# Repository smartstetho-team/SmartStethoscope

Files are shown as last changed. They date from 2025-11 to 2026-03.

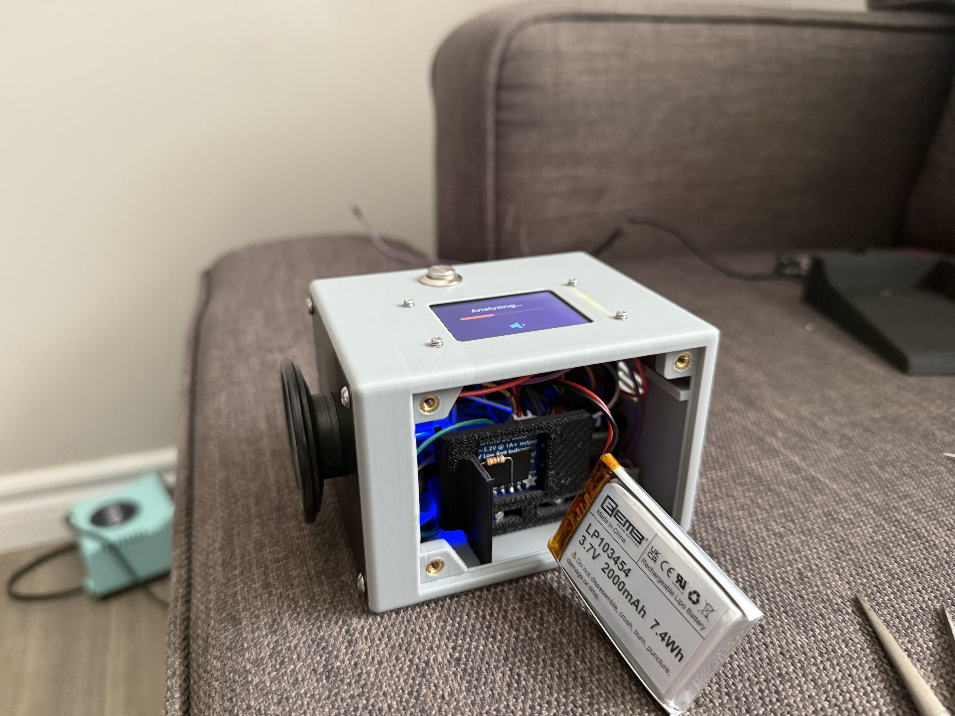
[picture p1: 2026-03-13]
software/team-website/cardioScope.jpg

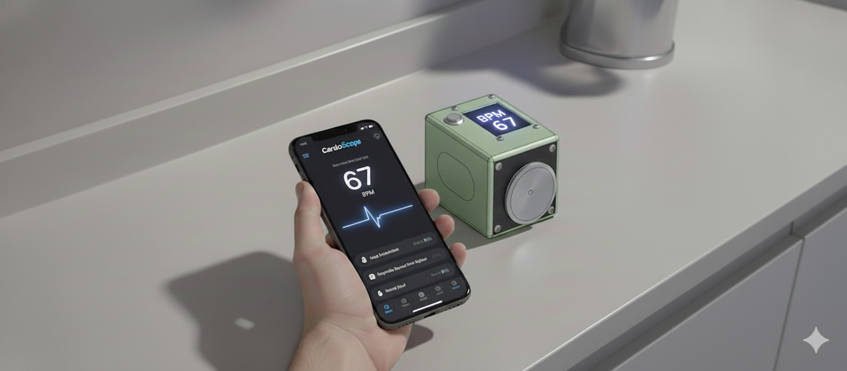
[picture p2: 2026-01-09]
software/team-website/cardioScope.png

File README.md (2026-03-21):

<div align="center">
  CardioScope Logo

  # CardioScope
  **University of Waterloo | Mechatronics Engineering Capstone 2026**

  
  

  *An intelligent digital stethoscope designed for real-time heart sound analysis*
</div>

---

## 🩺 Project Overview
Cardiovascular disease is a leading cause of death globally, yet traditional acoustic stethoscopes lack the ability to record or algorithmically analyze heart sounds. **CardioScope** is a handheld device designed to bridge this gap by augmenting traditional auscultation with digital capabilities. 

Our system enables users to record and screen heart sounds remotely, utilizing a machine learning pipeline to flag potential irregularities like murmurs. By providing accessible, intelligent diagnostics, CardioScope assists users in determining when to seek professional medical care, particularly in low-resource or remote settings.

### 🚀 Key Objectives
* **Handheld Augmentation:** A compact (~200g), ergonomic device integrated with a custom-machined chest piece.
* **Intelligent Screening:** A digital pipeline targeting ≥60% sensitivity and specificity for detecting cardiac abnormalities.
* **Real-Time Connectivity:** Wireless streaming via Bluetooth Low Energy (BLE) to a companion React Native mobile app.
* **Performance Constraints:** Designed for a target build cost of ~$300 with at least one hour of continuous operation.

## 🛠️ Technical Stack
* **Core Hardware:** ESP32-S3 microcontroller, MAX4466 analog microphone, and a Waveshare 2-inch LCD for live visualization.
* **Power Management:** 3.7V LiPo battery paired with a PowerBoost 1000C module.
* **Software Framework:** Firmware written in C++ with FreeRTOS; mobile interface developed in React Native.
* **ML Pipeline:** Python-based digital filtering, feature extraction, and classification models for anomaly detection.

## 🖼️ Demonstration

<div align="center">
  CardioScope Final Prototype

  ### 📺 Project Walkthrough
  
</div>

## ⏭️ Next Steps

Future work will focus on improving the experience during device operation:

* **Multimodal Recording Feedback:** Add haptic or auditory cues (vibration or a beep) to signal when a recording starts and stops, so users aren't solely dependent on the LCD notifications.

* **Live Placement Guidance:** Add a real-time arrow system on the LCD that uses signal strength to guide the user into the optimal chest position. Once a strong signal is detected, the device simply notifies the user that they've found the right spot.

## 👥 The Team
We are final-year Mechatronics Engineering students at the University of Waterloo:
* **Krish Vijayan**
* **Om Patel**
* **Roby Aldave Garza**
* **Rijin Muralidharan**

---

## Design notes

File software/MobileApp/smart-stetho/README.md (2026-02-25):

Install dependencies:
`npm install`

Rebuild:
`npx expo prebuild --clean`

Run app:
`npx expo run:ios --device`

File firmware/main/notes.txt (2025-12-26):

Design related notes:

Audio Sampling Task:
// TODO: This design may change?
// Should we allow users to record new sounds if lets say we finish BLE streaming before
// ML classification? In this case, recorded sounds will be in a queue (complex).

Both BLE and ML classification task will have a ptr to the master audio buffer containing
all the bytes from the recording. 
As long as YOU DO NOT modify the buffer at that address, you should be able to read the data
from both tasks. It is immutable atm. If you need to modify it, use mutexes for thread safety
or use a seperate buffer.

Code comments:

- Use ESP_LOGI for printing.
- If UART driver/hardware is slow compared to the cpu, then there is a chance that
  the print wont come out properly. So you can make the CPU wait until the UART driver
  is done pushing out all the characters on the Tx pin before proceeding. This is equivalent
  to fflush after printf.
  - Force flush after ESP_LOGI --> uart_wait_tx_done(UART_NUM_0, portMAX_DELAY);

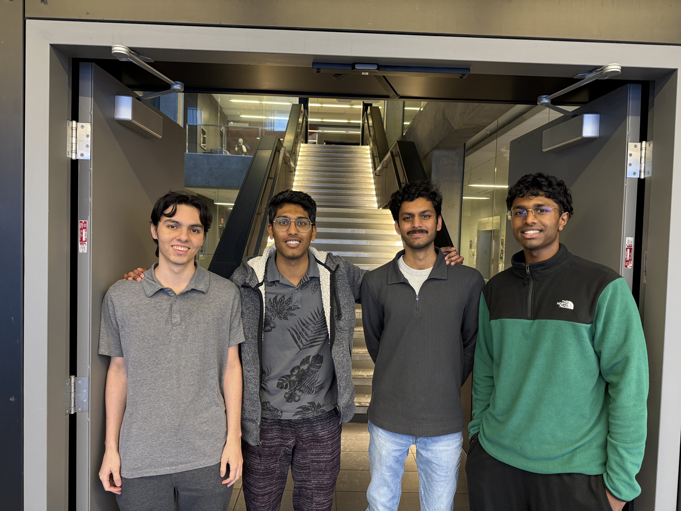
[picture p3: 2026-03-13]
software/team-website/team_photo.jpg

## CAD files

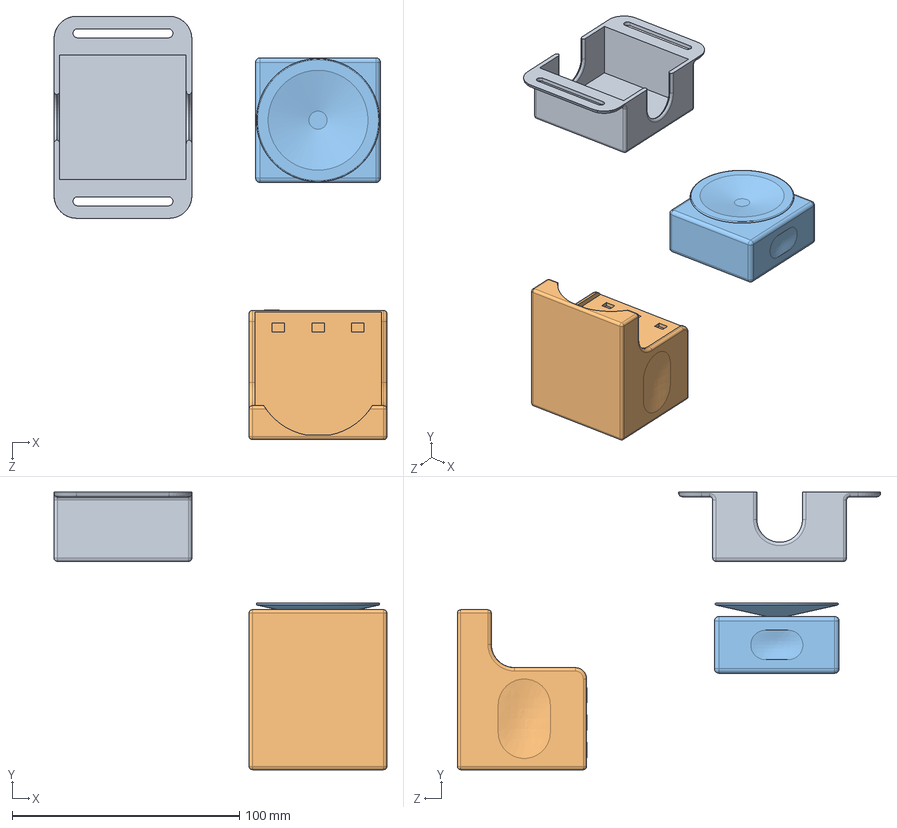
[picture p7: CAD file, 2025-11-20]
mechanical/V1 modular/SmartStetho.SLDASM
146.7 x 122.2 x 186.5 mm
module
holder
wearable

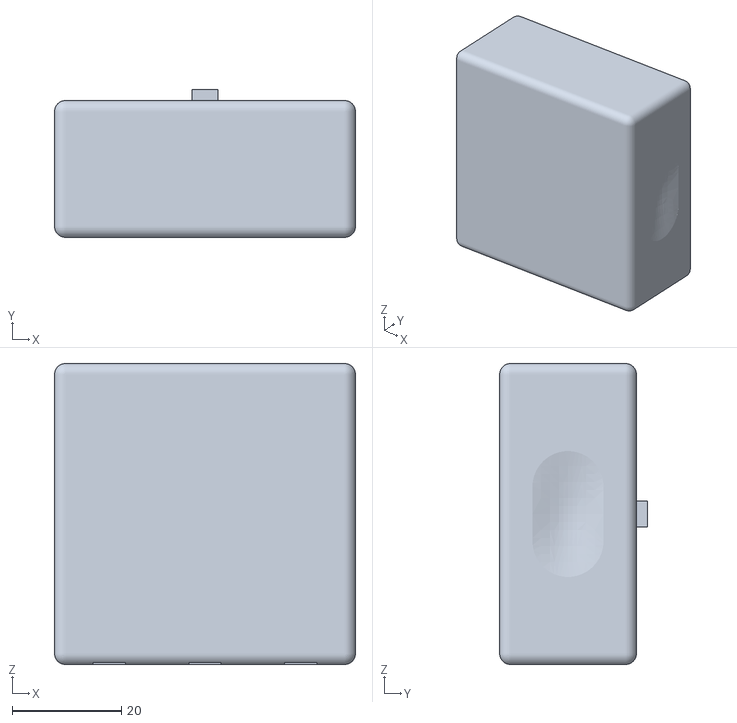
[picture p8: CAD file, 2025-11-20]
mechanical/V1 modular/dummy 3dp/box.STL
55.0 x 27.0 x 55.0

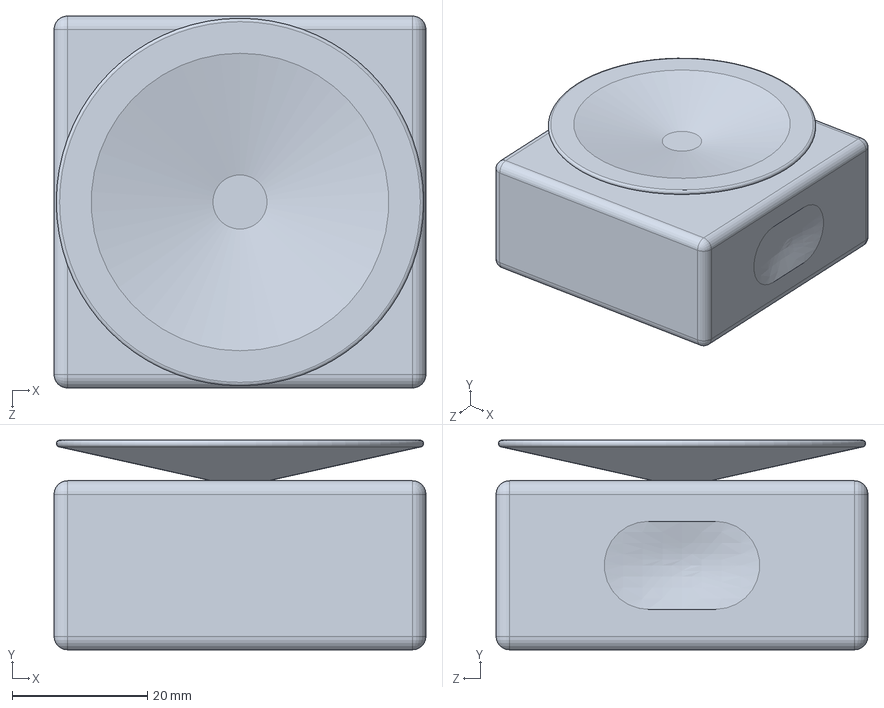
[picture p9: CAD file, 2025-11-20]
mechanical/V1 modular/module.SLDPRT
55.0 x 31.0 x 55.0 mm

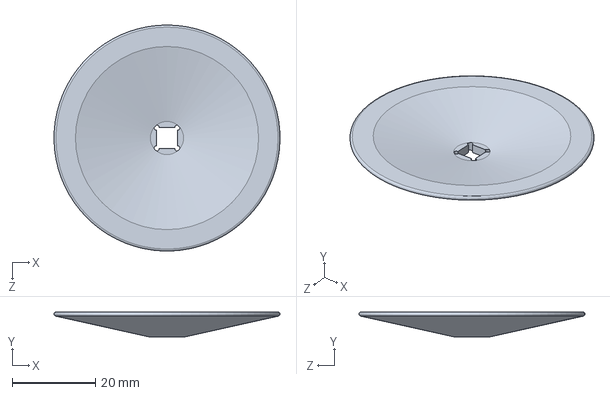
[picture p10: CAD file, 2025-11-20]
mechanical/V1 modular/dummy 3dp/module - Copy.SLDPRT
54.3 x 6.00 x 54.3 mm

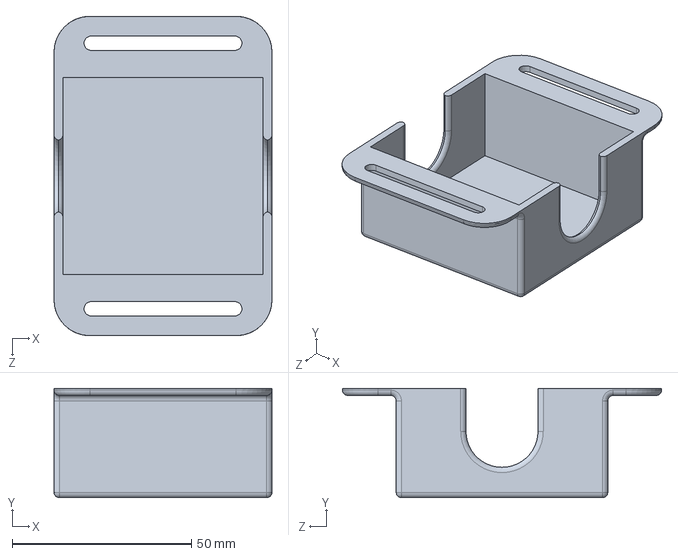
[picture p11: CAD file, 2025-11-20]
mechanical/V1 modular/wearable.SLDPRT
60.8 x 30.5 x 89.0 mm

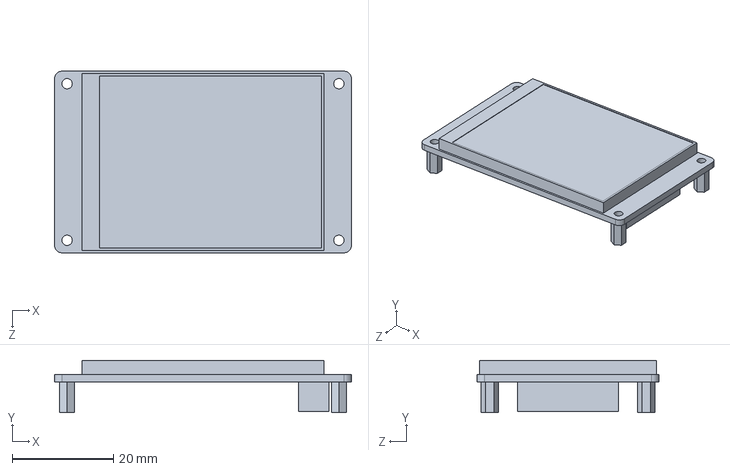
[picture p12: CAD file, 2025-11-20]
mechanical/V3/Screen.SLDPRT
58.8 x 10.3 x 36.0 mm

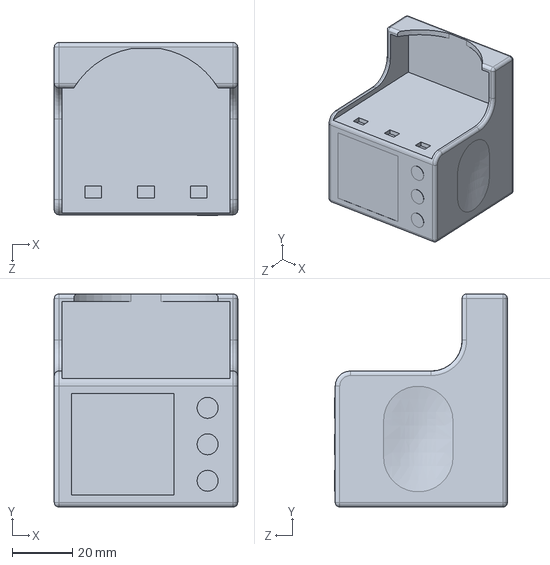
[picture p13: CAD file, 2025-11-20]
mechanical/V1 modular/holder.SLDPRT
60.8 x 70.5 x 57.2 mm

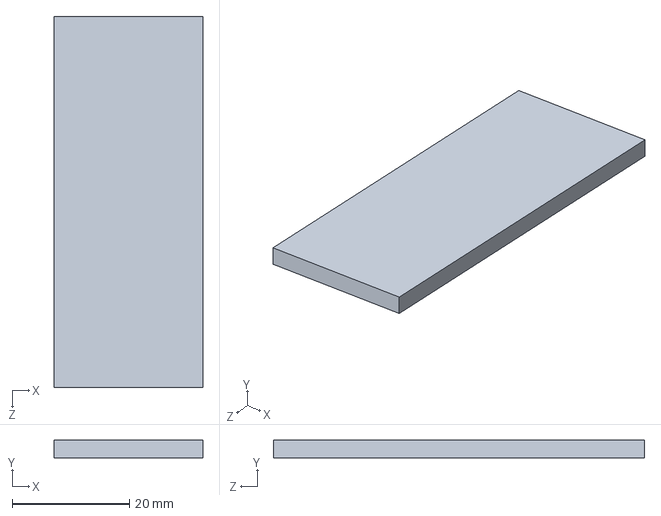
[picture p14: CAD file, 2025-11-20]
mechanical/V3/esp.SLDPRT
25.4 x 3.00 x 63.3 mm

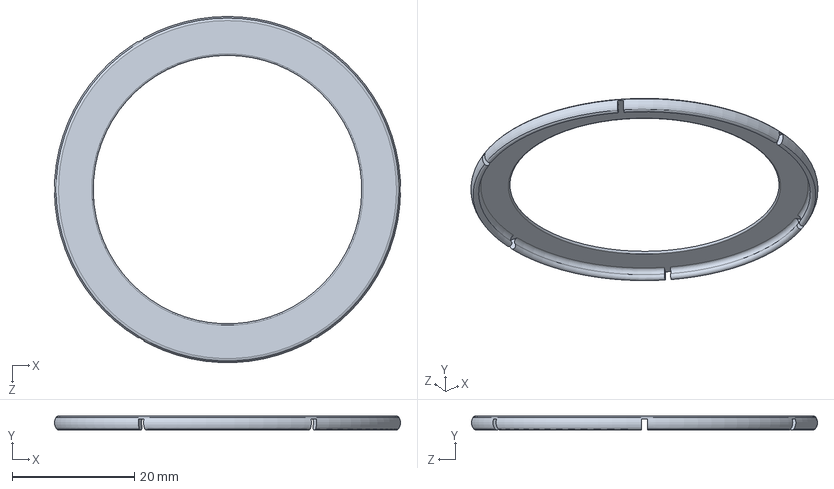
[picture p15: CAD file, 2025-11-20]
mechanical/V1 modular/clip.SLDPRT
56.5 x 2.31 x 56.5 mm

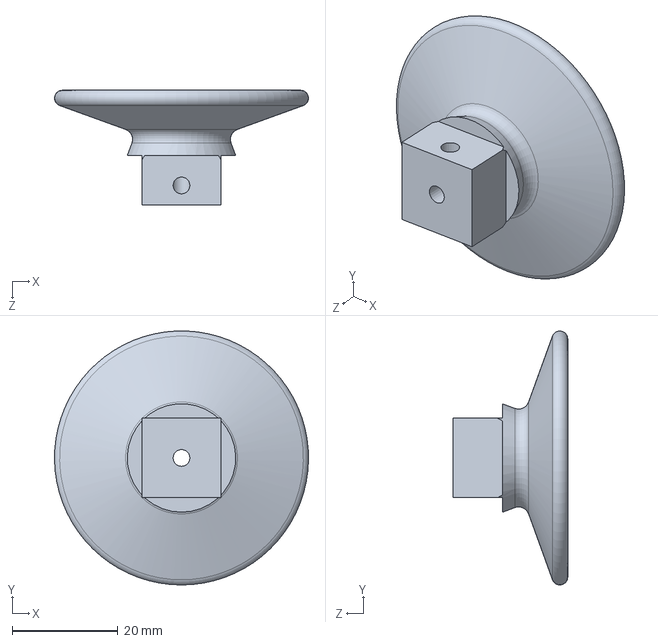
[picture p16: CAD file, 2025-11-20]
mechanical/V3/ChestPiece.SLDPRT
48.0 x 48.0 x 21.6 mm

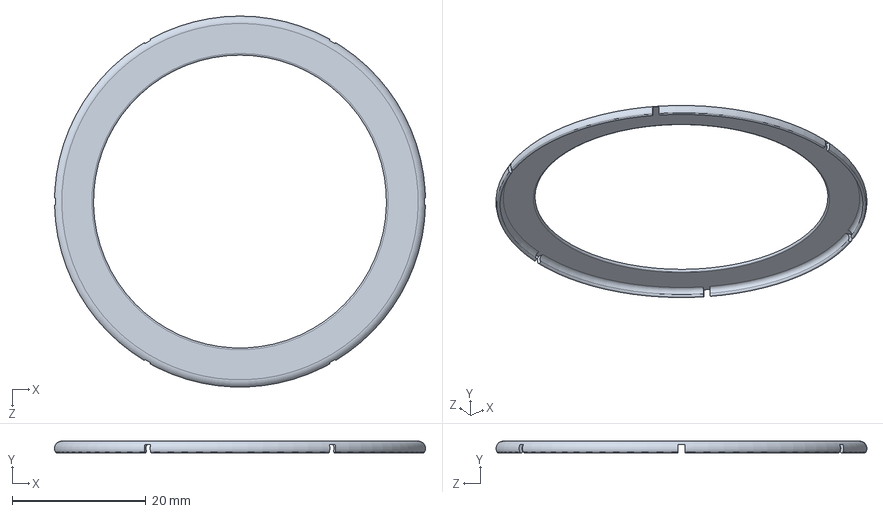
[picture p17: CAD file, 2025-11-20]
mechanical/V1 modular/Part1.SLDPRT
55.5 x 1.77 x 55.5 mm

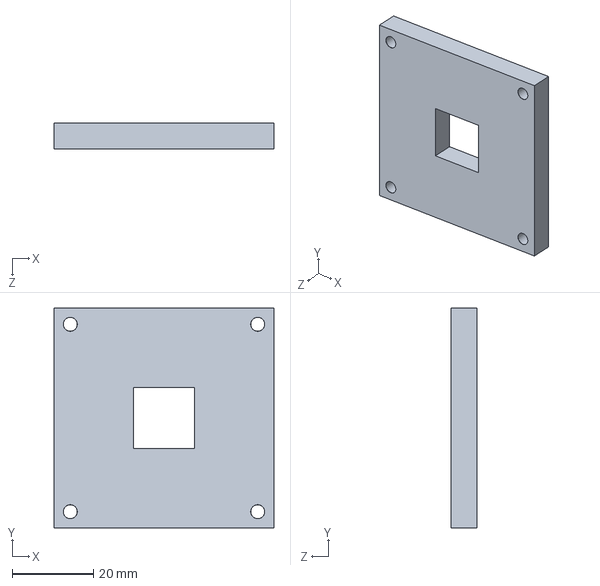
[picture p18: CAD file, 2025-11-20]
mechanical/V3/facePlate.SLDPRT
54.0 x 54.0 x 6.35 mm

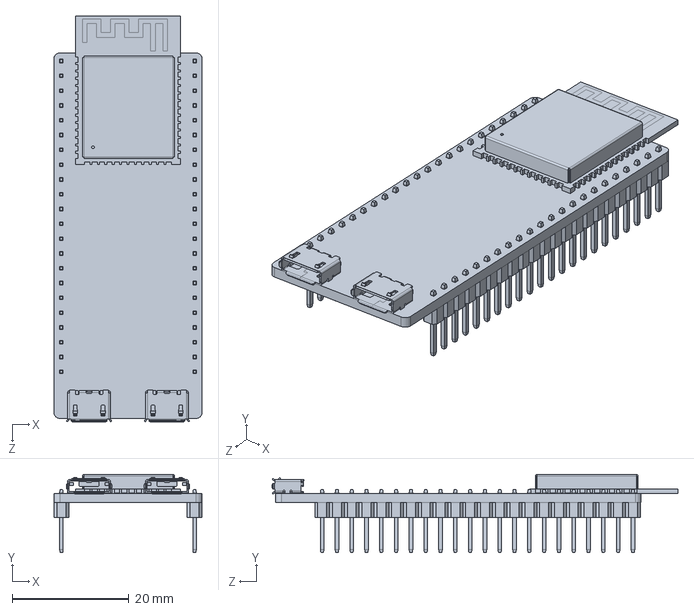
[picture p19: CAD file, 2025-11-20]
mechanical/V3/esp2.SLDPRT
25.4 x 13.4 x 69.6 mm

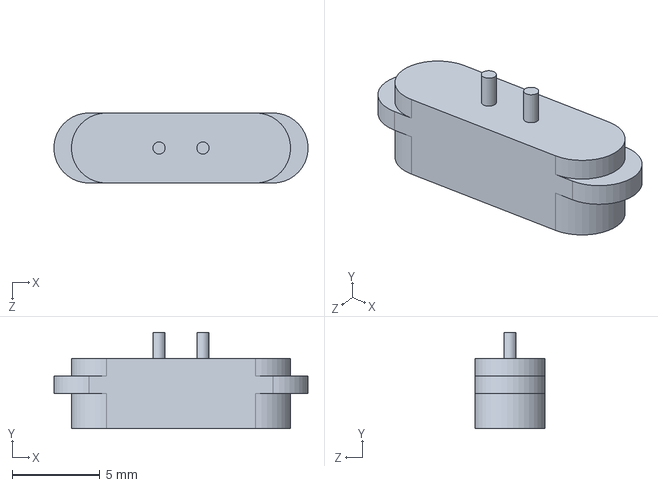
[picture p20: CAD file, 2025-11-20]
mechanical/V3/pogo.SLDPRT
14.5 x 5.50 x 4.00 mm

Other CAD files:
mechanical/V3/TopLevel.SLDASM
mechanical/V3/Mic.SLDPRT
mechanical/V3/adapter.SLDPRT
mechanical/V3/Button.SLDPRT
mechanical/V1 modular/dummy 3dp/module - Copy - Copy.SLDPRT
mechanical/V1 modular/dummy 3dp/module - Copy.STL
mechanical/V3/92095A460_Button Head Hex Drive Screw.SLDPRT
mechanical/V3/BodyPlastic.SLDPRT
mechanical/V3/battery.SLDPRT

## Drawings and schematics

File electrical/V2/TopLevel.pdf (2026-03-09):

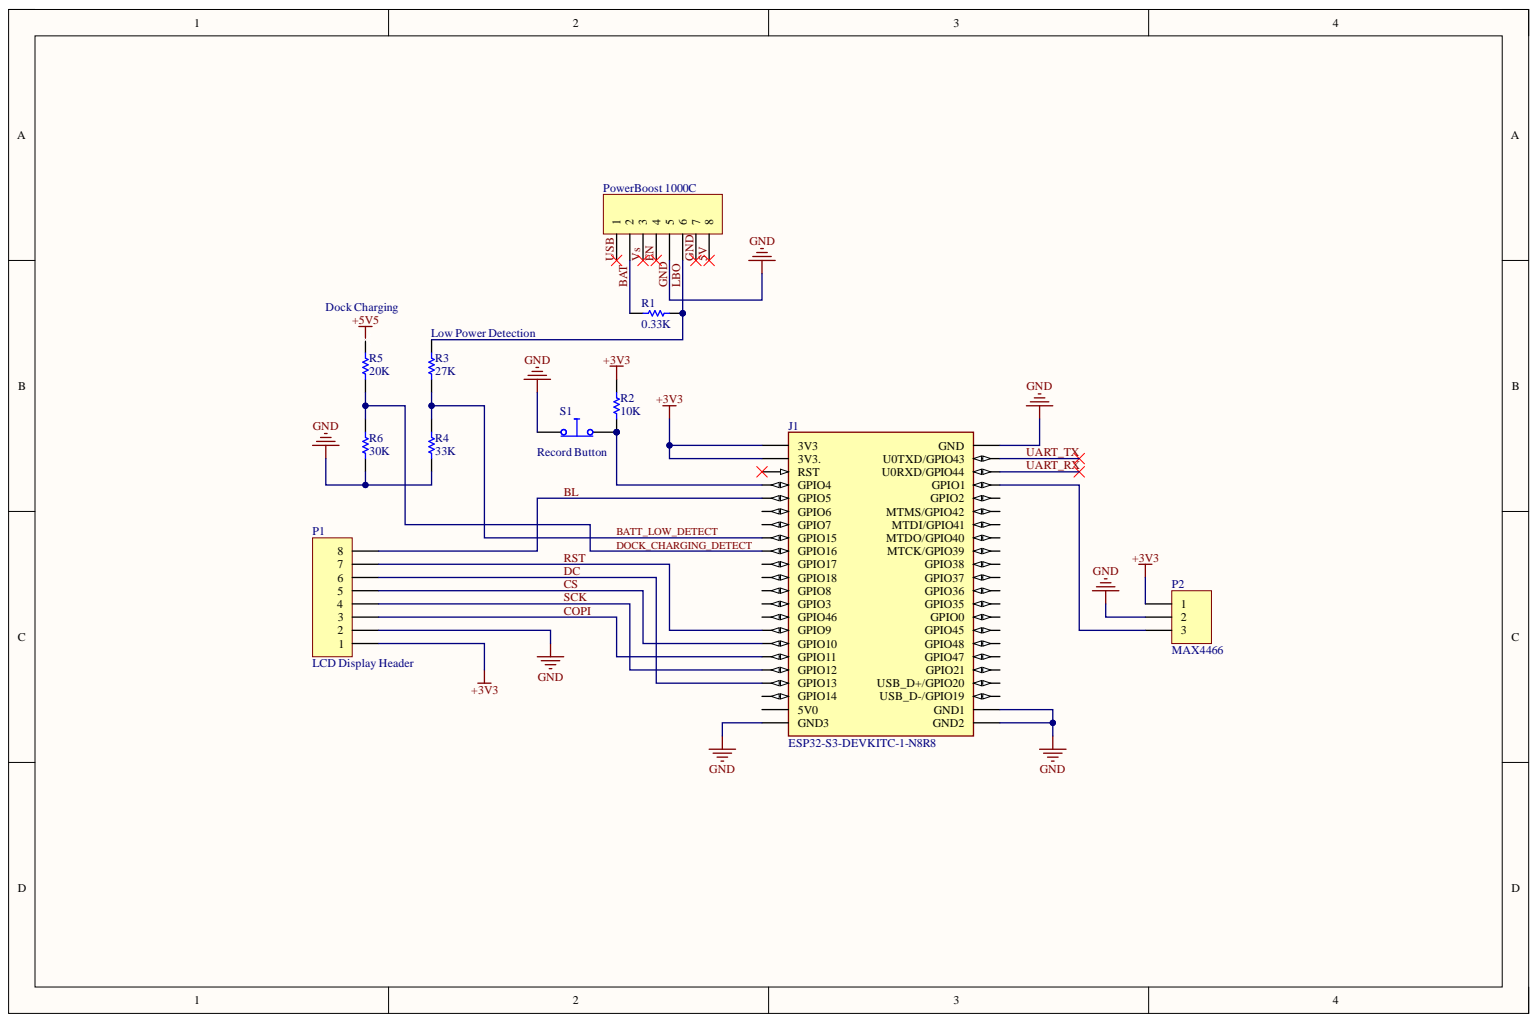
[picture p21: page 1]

Header

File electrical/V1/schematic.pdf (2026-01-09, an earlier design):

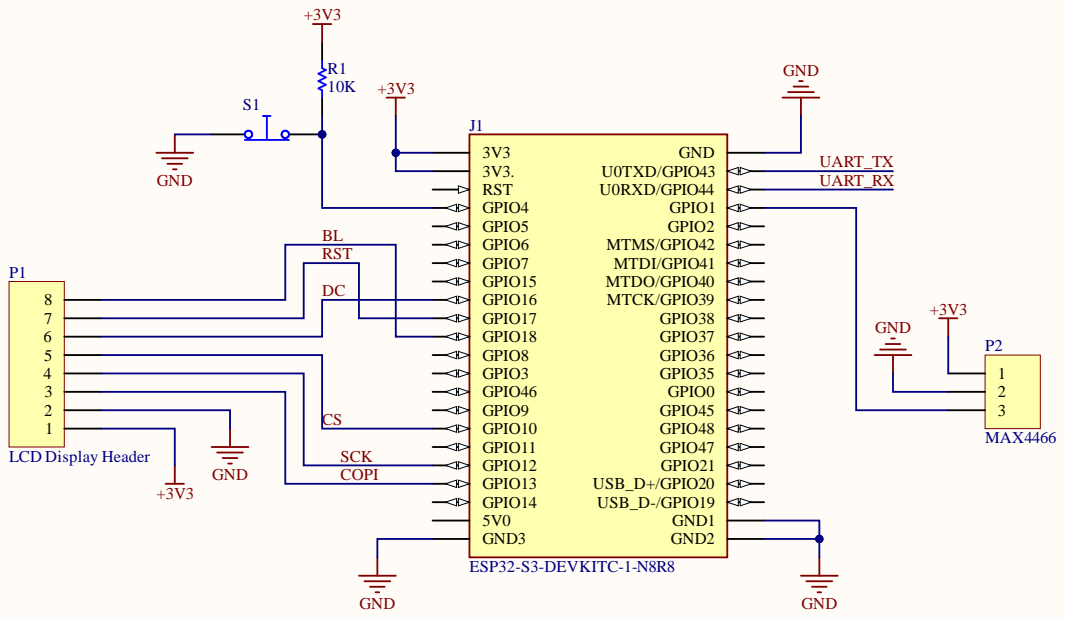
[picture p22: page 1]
RST GPIO

Header | | SCK

G N D COPI

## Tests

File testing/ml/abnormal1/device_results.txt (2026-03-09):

[AI] Logits: -0.479748, -0.251313
[AI] Probabilities: 0.443138, 0.556862

=== Results ===
P(Normal):  0.4431
P(Murmur):  0.5569
Verdict:    ABNORMAL

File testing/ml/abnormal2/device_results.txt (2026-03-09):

[AI] Logits: -4.493242, 3.952250
[AI] Probabilities: 0.013215, 0.986785

=== Results ===
P(Normal):  0.0132
P(Murmur):  0.9868
Verdict:    ABNORMAL

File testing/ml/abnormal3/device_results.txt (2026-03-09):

[AI] Logits: -3.028471, 1.376829
[AI] Probabilities: 0.012065, 0.987935

=== Results ===
P(Normal):  0.0121
P(Murmur):  0.9879
Verdict:    ABNORMAL

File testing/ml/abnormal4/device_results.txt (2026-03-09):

[AI] Probabilities: 0.008667, 0.991333

=== Results ===
P(Normal):  0.0087
P(Murmur):  0.9913
Verdict:    ABNORMAL

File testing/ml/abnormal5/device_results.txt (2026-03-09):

[AI] Probabilities: 0.854812, 0.145188

=== Results ===
P(Normal):  0.8548
P(Murmur):  0.1452
Verdict:    NORMAL

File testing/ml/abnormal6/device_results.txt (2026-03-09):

[AI] Probabilities: 0.077212, 0.922788

=== Results ===
P(Normal):  0.0772
P(Murmur):  0.9228
Verdict:    ABNORMAL

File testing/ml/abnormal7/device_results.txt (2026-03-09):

[AI] Probabilities: 0.000000, 1.000000

=== Results ===
P(Normal):  0.0000
P(Murmur):  1.0000
Verdict:    ABNORMAL

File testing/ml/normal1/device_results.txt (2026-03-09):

[AI] Logits: 0.379348, -1.368702
[AI] Probabilities: 0.851707, 0.148293

=== Results ===
P(Normal):  0.8517
P(Murmur):  0.1483
Verdict:    NORMAL

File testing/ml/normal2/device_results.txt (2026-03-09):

[AI] Logits: -0.037150, -0.794605
[AI] Probabilities: 0.680801, 0.319199

=== Results ===
P(Normal):  0.6808
P(Murmur):  0.3192
Verdict:    NORMAL

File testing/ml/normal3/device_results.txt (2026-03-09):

[AI] Logits: 0.726557, -1.476762
[AI] Probabilities: 0.900547, 0.099453

=== Results ===
P(Normal):  0.9005
P(Murmur):  0.0995
Verdict:    NORMAL

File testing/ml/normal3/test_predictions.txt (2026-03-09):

murmur	prediction	no_murmur_prob	murmur_prob
Absent	No Murmur	0.9959	0.0041

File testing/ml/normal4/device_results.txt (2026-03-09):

[AI] Before GAP: len=19
[AI] Logits: 1.053913, -1.894638
[AI] Probabilities: 0.950195, 0.049805

=== Results ===
P(Normal):  0.9502
P(Murmur):  0.0498
Verdict:    NORMAL

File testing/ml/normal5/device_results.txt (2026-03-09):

[AI] Logits: 0.590845, -1.554227
[AI] Probabilities: 0.895207, 0.104793

=== Results ===
P(Normal):  0.8952
P(Murmur):  0.1048
Verdict:    NORMAL

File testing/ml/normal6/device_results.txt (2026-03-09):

[AI] Logits: 1.027027, -1.891056
[AI] Probabilities: 0.948733, 0.051267

=== Results ===
P(Normal):  0.9487
P(Murmur):  0.0513
Verdict:    NORMAL

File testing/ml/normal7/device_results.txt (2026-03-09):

[AI] Logits: 0.723974, -1.576599
[AI] Probabilities: 0.908924, 0.091076

=== Results ===
P(Normal):  0.9089
P(Murmur):  0.0911
Verdict:    NORMAL

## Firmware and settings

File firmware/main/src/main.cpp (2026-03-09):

#include "drivers/button.h"
#include "drivers/lcd_display.h"
#include "drivers/power_mgmt.h"
#include "cmn.h"
#include "mic_setup.h"
#include "ble_setup.h"
#include "dsp_ml_setup.h"
#include "lcd_ui_setup.h"
#include "debug.h"

#include <stdio.h>
#include <string.h>
#include <esp_heap_caps.h>
#include "freertos/FreeRTOS.h"
#include "freertos/task.h"
#include "esp_adc/adc_continuous.h"
#include "esp_log.h"
#include "lvgl.h"
#include "NimBLEDevice.h"

// Global variables
static const char *MAIN_TAG = "MAIN";

task_params task_parameters = 
{
    .master_audio_buffer = NULL,
    .filtered_audio_buffer = NULL,
    .audio_dc_offset = 0,
    .mic_adc_handle = NULL,
    .event_group_handle = NULL,
    .inference_buffer_a = NULL,
    .inference_buffer_b = NULL,
    .inference_buffer_skip = NULL,
    .pHeartChar = NULL,
    .pAudioDataChar = NULL,
    .pBatteryChar = NULL,
};

TaskHandle_t audio_sampling_task_handle = NULL;
TaskHandle_t ble_streaming_task_handle = NULL;
TaskHandle_t ml_classification_task_handle = NULL;
TaskHandle_t lcd_ui_task_handle = NULL;
TaskHandle_t debug_task_handle = NULL;

// Characteristics need to be accessible inside the loop
NimBLECharacteristic* pHeartChar = NULL;
NimBLECharacteristic* pAudioDataChar = NULL; 
NimBLECharacteristic* pBatteryChar = NULL;

// BLE Callbacks
class MyCommandCallbacks : public NimBLECharacteristicCallbacks {
    // Note the added NimBLEConnInfo parameter
    void onWrite(NimBLECharacteristic* pCharacteristic, NimBLEConnInfo& connInfo) override {
        std::string value = pCharacteristic->getValue();
        
        if (value == "RESET") {
            ESP_LOGW("BLE", "Remote Reset Command Received! Rebooting...");
            // Delay to allow BLE ACK to send before the CPU dies
            vTaskDelay(pdMS_TO_TICKS(500)); 
            esp_restart(); 
        }
    }
};
class MyServerCallbacks : public NimBLEServerCallbacks {
    void onConnect(NimBLEServer* pServer, NimBLEConnInfo& connInfo) override {
        ESP_LOGI(MAIN_TAG, "iPhone Connected!");
    };
    void onDisconnect(NimBLEServer* pServer, NimBLEConnInfo& connInfo, int reason) override {
        ESP_LOGI(MAIN_TAG, "Disconnected. Restarting Advertising...");
        NimBLEDevice::startAdvertising();
    }
};

extern "C" void app_main(void) 
{
    // Set up driver for serial debugging
    debug_init();

    // Set up mutex for LVGL resources
    _lock_init(&task_parameters.lcd_params.lvgl_api_lock);

    // Configure LCD display
    configure_lcd_display(&task_parameters.lcd_params);

    // Configure LVGL library and timer
    configure_lcd_lvgl(&task_parameters.lcd_params);

    // Initialize bootup screen
    bootup_screen_init((void*)&task_parameters.lcd_params);

    // Create event group so tasks can talk with each other
    task_parameters.event_group_handle = xEventGroupCreate();

    if (task_parameters.event_group_handle == NULL)
    {
        ESP_LOGE(MAIN_TAG, "Can't create group event handle!");
    }

    // Configure Mic ADC
    configure_mic_adc(&task_parameters.mic_adc_handle);
    
    ESP_LOGI(MAIN_TAG, "PSRAM Size Before: %d", heap_caps_get_free_size(MALLOC_CAP_SPIRAM));

    // Allocate space for audio buffer in external RAM
    task_parameters.master_audio_buffer = (uint8_t*)heap_caps_malloc
                                          (MASTER_AUDIO_BUFFER_SIZE, MALLOC_CAP_SPIRAM);

    // Allocate space for filtered audio buffer in external RAM
    // Note: Size is halved since we only need ADC value instead of the whole packet
    task_parameters.filtered_audio_buffer = (float*)heap_caps_malloc
                                            (NUM_OF_SAMPLES * sizeof(float), MALLOC_CAP_SPIRAM);

    task_parameters.inference_buffer_a = (float*)heap_caps_malloc(2200000, MALLOC_CAP_SPIRAM);
    task_parameters.inference_buffer_b = (float*)heap_caps_malloc(2200000, MALLOC_CAP_SPIRAM);
    task_parameters.inference_buffer_skip = (float*)heap_caps_malloc(2200000, MALLOC_CAP_SPIRAM);


    if (task_parameters.master_audio_buffer == NULL || 
        task_parameters.filtered_audio_buffer == NULL ||
        task_parameters.inference_buffer_a == NULL ||
        task_parameters.inference_buffer_b == NULL || 
        task_parameters.inference_buffer_skip == NULL)
    {
        ESP_LOGE(MAIN_TAG, "PSRAM Allocation Failed! Critical Error. \\
                 Current Free PSRAM: %d bytes", heap_caps_get_free_size(MALLOC_CAP_SPIRAM));

        while(1) 
        { 
            vTaskDelay(pdMS_TO_TICKS(1000)); 
        }
    }

    ESP_LOGI(MAIN_TAG, "PSRAM Size After: %d", heap_caps_get_free_size(MALLOC_CAP_SPIRAM));

    // Set up BLE stack
    NimBLEDevice::init("SmartStetho-S3");
    NimBLEDevice::setMTU(512); 

    NimBLEServer* pServer = NimBLEDevice::createServer();
    pServer->setCallbacks(new MyServerCallbacks());

    // Services
    NimBLEService* pBatteryService = pServer->createService("180f");
    pBatteryChar = pBatteryService->createCharacteristic("2a19", NIMBLE_PROPERTY::READ | NIMBLE_PROPERTY::NOTIFY);
    pBatteryService->start();

    NimBLEService* pHeartService = pServer->createService("180d");
    pHeartChar = pHeartService->createCharacteristic("2a37", NIMBLE_PROPERTY::NOTIFY);
    pHeartService->start();

    NimBLEService* pStethoService = pServer->createService(SERVICE_UUID_STETHO);
    pAudioDataChar = pStethoService->createCharacteristic(CHAR_UUID_AUDIO_DATA, NIMBLE_PROPERTY::NOTIFY);
    // ESP32 reset callback via BLE 
    NimBLECharacteristic* pCmdChar = pStethoService->createCharacteristic(
                                    "00005678-0000-1000-8000-00805f9b34fb", 
                                    NIMBLE_PROPERTY::WRITE | 
                                    NIMBLE_PROPERTY::WRITE_NR // Adds "Write No Response" support
                                 );
    pCmdChar->setCallbacks(new MyCommandCallbacks());

    pStethoService->start();

    // Advertising
    NimBLEAdvertising* pAdvertising = NimBLEDevice::getAdvertising();
    pAdvertising->addServiceUUID("180d");
    pAdvertising->addServiceUUID(SERVICE_UUID_STETHO); 
    pAdvertising->setName("SmartStetho-S3");
    pAdvertising->start();

    task_parameters.pAudioDataChar = pAudioDataChar;
    task_parameters.pBatteryChar = pBatteryChar;
    task_parameters.pHeartChar = pHeartChar;

    // Create all tasks
    xTaskCreatePinnedToCore(audio_sampling_task, "audio_sampling_task", 8192, 
                            (void*)&task_parameters, 5, &audio_sampling_task_handle, 0);

    BaseType_t rslt = xTaskCreatePinnedToCore(ml_classification_task, "ml_classification_task", 10240, 
                                            (void*)&task_parameters, 5, &ml_classification_task_handle, 1);
    if (rslt != pdPASS) 
    {
        ESP_LOGE(MAIN_TAG, "Failed to create ML Task! Error code: %d", rslt);
    }

    xTaskCreatePinnedToCore(ble_streaming_task, "ble_streaming_task", 8192, 
                        (void*)&task_parameters, 3, &ble_streaming_task_handle, 0);

    xTaskCreatePinnedToCore(lcd_ui_task, "lcd_ui_task", 10240, 
                            (void*)&task_parameters, 2, &lcd_ui_task_handle, 0);

    xTaskCreatePinnedToCore(debug_task, "debug_task", 8192, 
                            (void*)&task_parameters, 2, &debug_task_handle, 0);

    // Set up button for the audio task
    configure_push_button(audio_sampling_task_handle, (void*)&task_parameters);
    
    // Set up low power detection (let the lcd task handle this)
    configure_lbo_pin(lcd_ui_task_handle, (void*)&task_parameters);

    // Set up dock charging (let the lcd task handle this)
    configure_charging_pin(lcd_ui_task_handle, (void*)&task_parameters);
}

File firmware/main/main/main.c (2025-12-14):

#include "setup.h"

#include "freertos/FreeRTOS.h"
#include "freertos/task.h"
#include "freertos/queue.h"
#include "driver/adc.h"
#include "esp_timer.h"

#include <stdio.h>

void app_main(void)
{
    adc1_config_width(MIC_ADC_WIDTH_BIT);
    adc1_config_channel_atten(MIC_ADC_CHANNEL, MIC_ADC_ATTEN);

    // raw_audio_buffer = xQueueCreate(4096, sizeof(uint8_t));
    // dsp_audio_buffer = xQueueCreate(4096, sizeof(uint8_t));

    /* Set up all relevant tasks */
    xTaskCreate(audio_sampling_task, "audio_sampling_task", 8192, NULL, 1, NULL);
    xTaskCreate(ble_streaming_task, "ble_streaming_task", 8192, NULL, 5, NULL);
    xTaskCreate(dsp_ml_processing_task, "dsp_ml_processing_task", 8192, NULL, 5, NULL);
    xTaskCreate(lcd_ui_task, "lcd_ui_task", 8192, NULL, 5, NULL);
}

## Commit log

2025-11-20 V3 with updated displays, esp, mic, chestpiece
    [92095A460_Button Head Hex Drive Screw.SLDPRT, BodyPlastic.SLDPRT, Button.SLDPRT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]
2025-11-27 add record and filter
2025-12-22 Get adc values upon button press; need to packetize for other tasks
2025-12-23 added other tasks; adc read upon button press
2025-12-25 Added LCD SPI driver
2025-12-26 uncommented lcd task; bug with task timing
    [main.cpp]
2025-12-26 updated prints
2025-12-26 fixed priorities and added notes related to debug prints
    [audio_sampling_task.cpp, lcd_ui_task.cpp, main.cpp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]
2025-12-28 Added task for audio debugging and started filtering in fw; looked through current filtering methods in python
2026-01-04 added esp-dsp lib and basic filtering in fw
2026-01-09 added initial electrical schematic
    [SmartStethoscope.PrjPcb, TopLevel.SchDoc]
2026-01-19 initial commit for integrating ml model
    [partitions.csv]
2026-01-26 update ble stuffz
    [partitions.csv]
2026-02-03 updated filtering bug
2026-02-09 Integrated new ML model
    [partitions.csv]
2026-02-15 Added bpm metric for normal case
2026-02-18 Added low power detection; manually tested by pulling gpio pin to gnd
2026-02-20 Updated sampling freq and recording length; removed bugs
    [main.cpp, mic_setup.h]
2026-02-21 new model weights for 4000 hz and 8 secs audio recording
2026-02-23 Removed unneccessary prints
2026-02-25 button press->loading->display
2026-02-26 update filtering
2026-03-02 Added dock charging detection
2026-03-02 Update buffer allocation. Fixed crashing after reloading model
    [main.cpp, ml_classification_task.cpp]
2026-03-02 Fixed buffer allocation causing model to crash
    [main.cpp]
2026-03-05 add esp32 reset
2026-03-06 added v2 schematic
    [SmartStethoscope.PrjPcb, TopLevel.SchDoc]
2026-03-06 folder restructure
    [SmartStethoscope.PrjPcb, TopLevel.SchDoc]
2026-03-08 Added schematic files
    [SmartStethoscope.PrjPcb, TopLevel.SchDoc]
